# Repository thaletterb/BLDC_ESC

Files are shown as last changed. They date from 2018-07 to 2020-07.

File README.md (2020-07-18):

## MSP430 Brushless DC Motor Electronic Speed Controller 

Development of an MSP430 based electronic speed controller. 
* Controls a BLDC electric motor for speed/torque
* Trapezoidal control scheme (6 Step Commutation)

## Background 

* Electronic Speed Control (ESC) is an electronic circuit that controls and regulates the speed of an electric motor. 
* SIMONK ESCs are commonly used for applications such as quadcopters or RC cars
* The purpose of this project is to develop an MSP430 based ESC which replicates the functionality of an off the shelf controller

## Hardware Architecture 

* Current implementation:
  * HW Revision 2
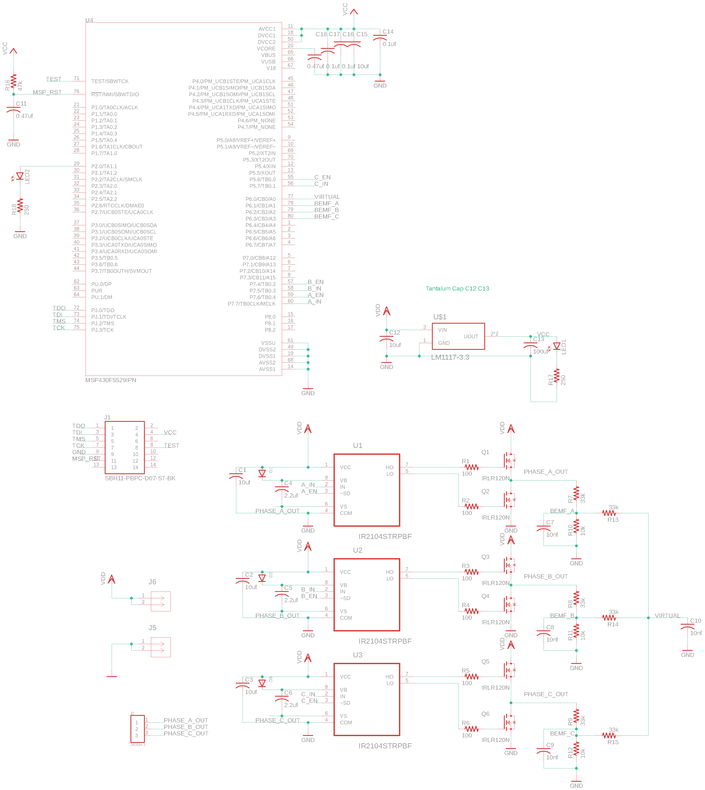
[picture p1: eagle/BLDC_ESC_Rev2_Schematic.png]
Title
  * 

* Revision History
  * Revision 2 
    * 1 MSP430F5529 PCBA 
    * 1 LHI 2212 920KV Brushless Motor
    * 6 IRLR120N MOSFET N Channel 
    * 3 IR2104S IC Gate Driver 
  * Revision 1 
    * 1 MSP430F5529 Launchpad
    * 1 LHI 2212 920KV Brushless Motor
    * 1 SIMONK 30A ESC
    * 1 Potentiometer to act as throttle input

## Software Architecture

* TI-RTOS
* Current phase of implementation consists of:
  * Using MSP430 to generate varying width PWM signals to the SIMONK ESC
  * Potentiometer attached to analog input P6.1
* Periodics
  * 50Hz CLK

## Software Requirements

Software is based on MSP430F5529 launchpad, running TI-RTOS.

* Code Composer Studio (ver 8.3.1)
  * http://www.ti.com/tool/CCSTUDIO
* TI-RTOS MSP43x 2.20.00.06 
  * http://software-dl.ti.com/dsps/dsps_public_sw/sdo_sb/targetcontent/tirtos/index.html

## References
* https://en.wikipedia.org/wiki/Electronic_speed_control 
* https://www.instructables.com/id/Make-Your-Own-ESC/ 
* http://www.ti.com/lit/ug/spruhu4e/spruhu4e.pdf
* https://simple-circuit.com/arduino-sensorless-bldc-motor-controller-esc/

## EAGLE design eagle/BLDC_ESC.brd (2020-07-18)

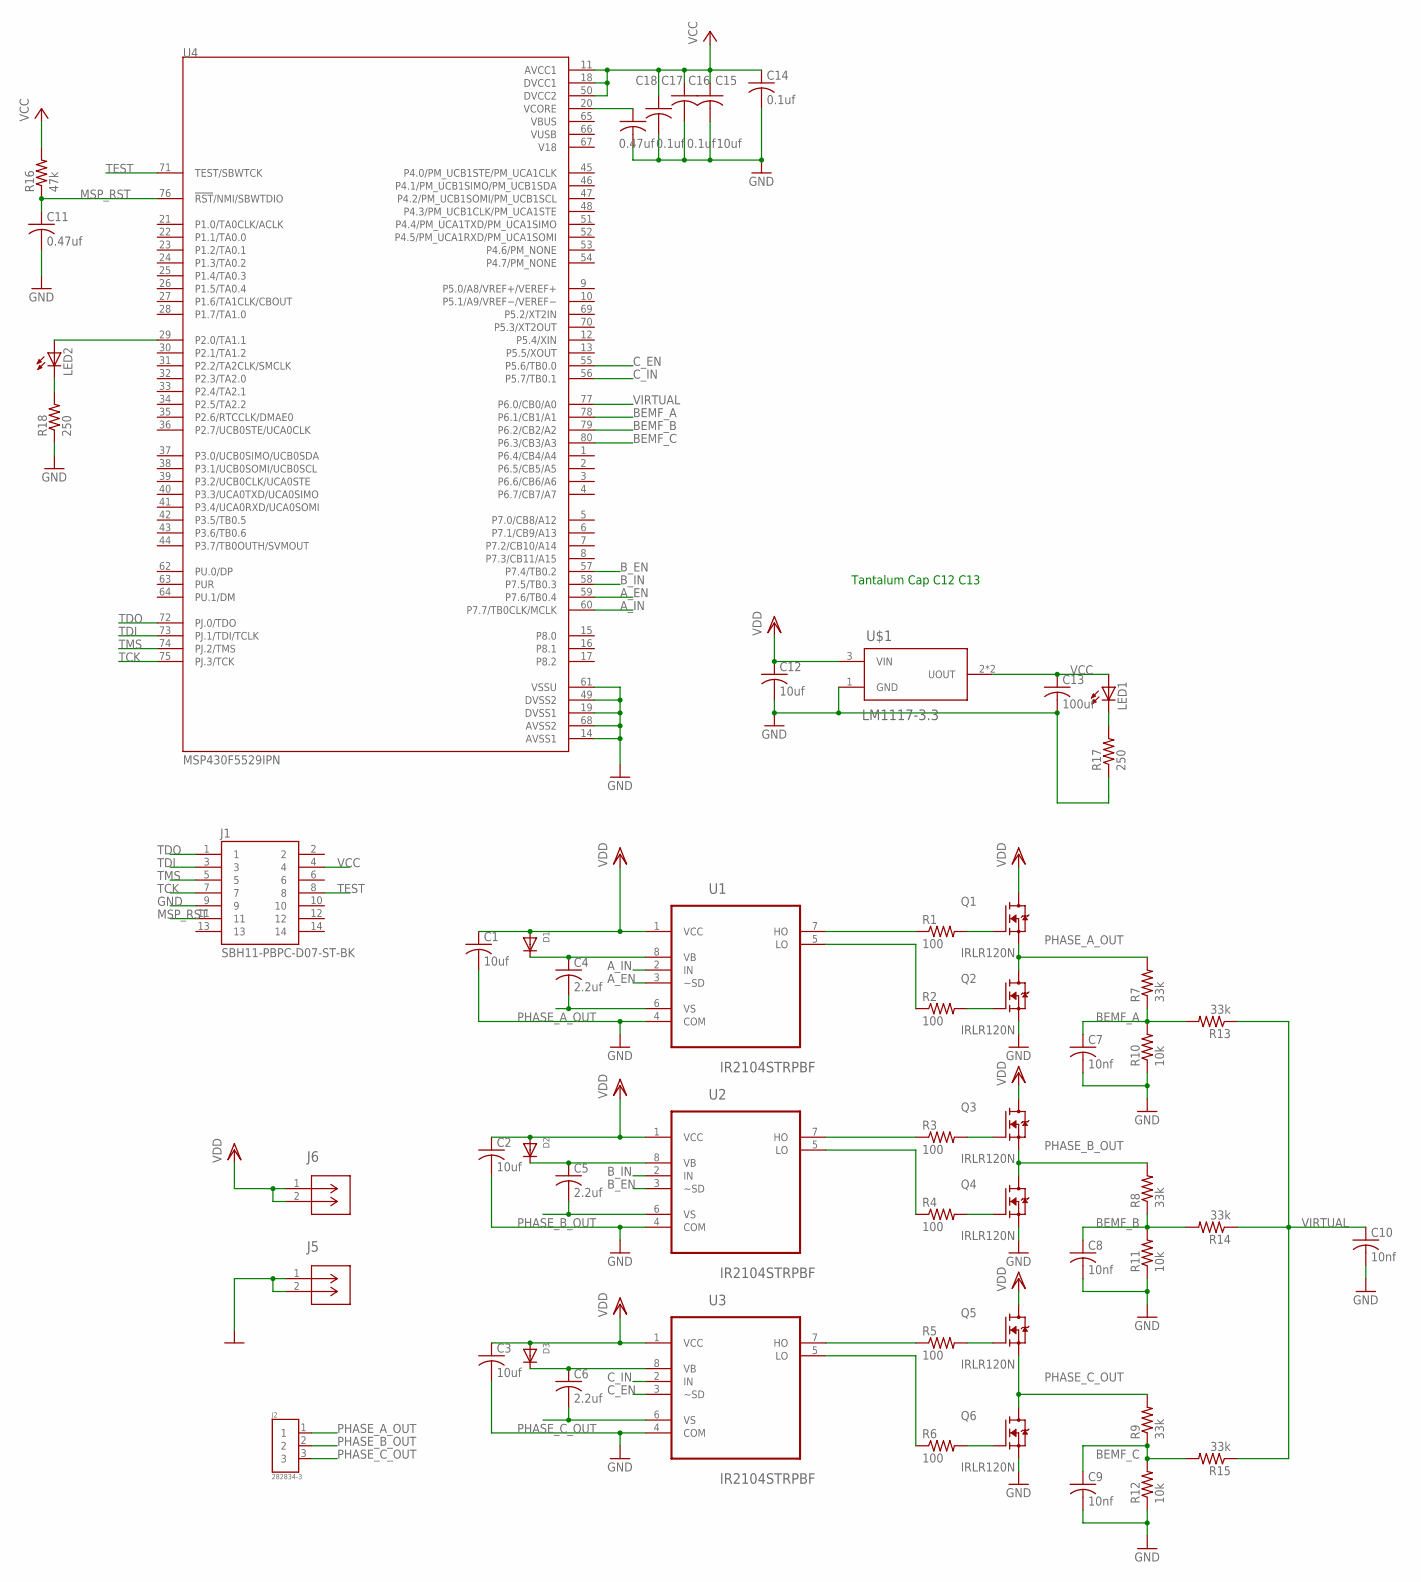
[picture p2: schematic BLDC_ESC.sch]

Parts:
C1, C2, C3: 10uf; C0805K
C4, C5, C6: 2.2uf; C0805K
C7, C8, C9, C10: 10nf; C0805
C11, C18: 0.47uf; C0805
C12, C15: 10uf; C0805
C13: 100uf; C0805
C14, C16, C17: 0.1uf; C0805
D1, D2, D3: DIODESOD-123; SOD-123
J1: SBH11-PBPC-D07-ST-BK; SULLINS_SBH11-PBPC-D07-ST-BK
J2: 282834-3; TE_282834-3
J5, J6: 105-1103-001; CONN_105-1102-001
LED1, LED2: LEDCHIPLED_0805; CHIPLED_0805
Q1, Q2, Q3, Q4, Q5, Q6: IRLR120N; DPAK229P990X239-3N
R1, R2, R3, R4, R5, R6: 100; R0805
R7, R8, R9, R13, R14, R15: 33k; R0805
R10, R11, R12: 10k; R0805
R16: 47k; M0805
R17, R18: 250; R0805
U1, U2, U3: IR2104STRPBF; SOIC127P600X175-8N
U4: MSP430F5529IPN; QFP50P1400X1400X160-80N
U$1: LM1117-3.3; SOT-223

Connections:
A_EN: U1.3 (~SD), U4.59 (P7.6/TB0.4)
A_IN: U1.2 (IN), U4.60 (P7.7/TB0CLK/MCLK)
BEMF_A: C7.1, R7.1, R10.2, R13.2, U4.78 (P6.1/CB1/A1)
BEMF_B: C8.1, R8.1, R11.2, R14.2, U4.79 (P6.2/CB2/A2)
BEMF_C: C9.1, R9.1, R12.2, R15.2, U4.80 (P6.3/CB3/A3)
B_EN: U2.3 (~SD), U4.57 (P7.4/TB0.2)
B_IN: U2.2 (IN), U4.58 (P7.5/TB0.3)
C_EN: U3.3 (~SD), U4.55 (P5.6/TB0.0)
C_IN: U3.2 (IN), U4.56 (P5.7/TB0.1)
GND: C1.2, C2.2, C3.2, C7.2, C8.2, C9.2, C10.2, C11.2, C12.2, C13.2, C14.2, C15.2, C16.2, C17.2, C18.2, J1.9, J5.1, J5.2, Q2.2 (S), Q4.2 (S), Q6.2 (S), R10.1, R11.1, R12.1, R17.1, R18.1, U1.4 (COM), U2.4 (COM), U3.4 (COM), U4.14 (AVSS1), U4.19 (DVSS1), U4.49 (DVSS2), U4.61 (VSSU), U4.68 (AVSS2), U$1.1 (GND)
MSP_RST: C11.1, J1.11, R16.1, U4.76 (!RST!/NMI/SBWTDIO)
unnamed: Q1.1 (G), R1.2
unnamed: R1.1, U1.7 (HO)
unnamed: R2.1, U1.5 (LO)
unnamed: Q2.1 (G), R2.2
unnamed: C6.1, D3.C, U3.8 (VB)
unnamed: C5.1, D2.C, U2.8 (VB)
unnamed: C4.1, D1.C, U1.8 (VB)
unnamed: R3.1, U2.7 (HO)
unnamed: Q3.1 (G), R3.2
unnamed: R4.1, U2.5 (LO)
unnamed: Q4.1 (G), R4.2
unnamed: R5.1, U3.7 (HO)
unnamed: Q5.1 (G), R5.2
unnamed: R6.1, U3.5 (LO)
unnamed: Q6.1 (G), R6.2
unnamed: LED1.C, R17.2
unnamed: LED2.A, U4.29 (P2.0/TA1.1)
unnamed: LED2.C, R18.2
unnamed: C18.1, U4.20 (VCORE)
PHASE_A_OUT: C4.2, J2.1, Q1.2 (S), Q2.3 (D), R7.2, U1.6 (VS)
PHASE_B_OUT: C5.2, J2.2, Q3.2 (S), Q4.3 (D), R8.2, U2.6 (VS)
PHASE_C_OUT: C6.2, J2.3, Q5.2 (S), Q6.3 (D), R9.2, U3.6 (VS)
TCK: J1.7, U4.75 (PJ.3/TCK)
TDI: J1.3, U4.73 (PJ.1/TDI/TCLK)
TDO: J1.1, U4.72 (PJ.0/TDO)
TEST: J1.8, U4.71 (TEST/SBWTCK)
TMS: J1.5, U4.74 (PJ.2/TMS)
V18: U4.67 (V18)
VBUS: U4.65 (VBUS)
VCC: C13.1, C14.1, C15.1, C16.1, C17.1, J1.4, LED1.A, R16.2, U4.11 (AVCC1), U4.18 (DVCC1), U4.50 (DVCC2), U$1.2 (UOUT), U$1.4 (UOUT)
VDD: C1.1, C2.1, C3.1, C12.1, D1.A, D2.A, D3.A, J6.1, J6.2, Q1.3 (D), Q3.3 (D), Q5.3 (D), U1.1 (VCC), U2.1 (VCC), U3.1 (VCC), U$1.3 (VIN)
VIRTUAL: C10.1, R13.1, R14.1, R15.1, U4.77 (P6.0/CB0/A0)
VUSB: U4.66 (VUSB)

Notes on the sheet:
Tantalum Cap C12 C13

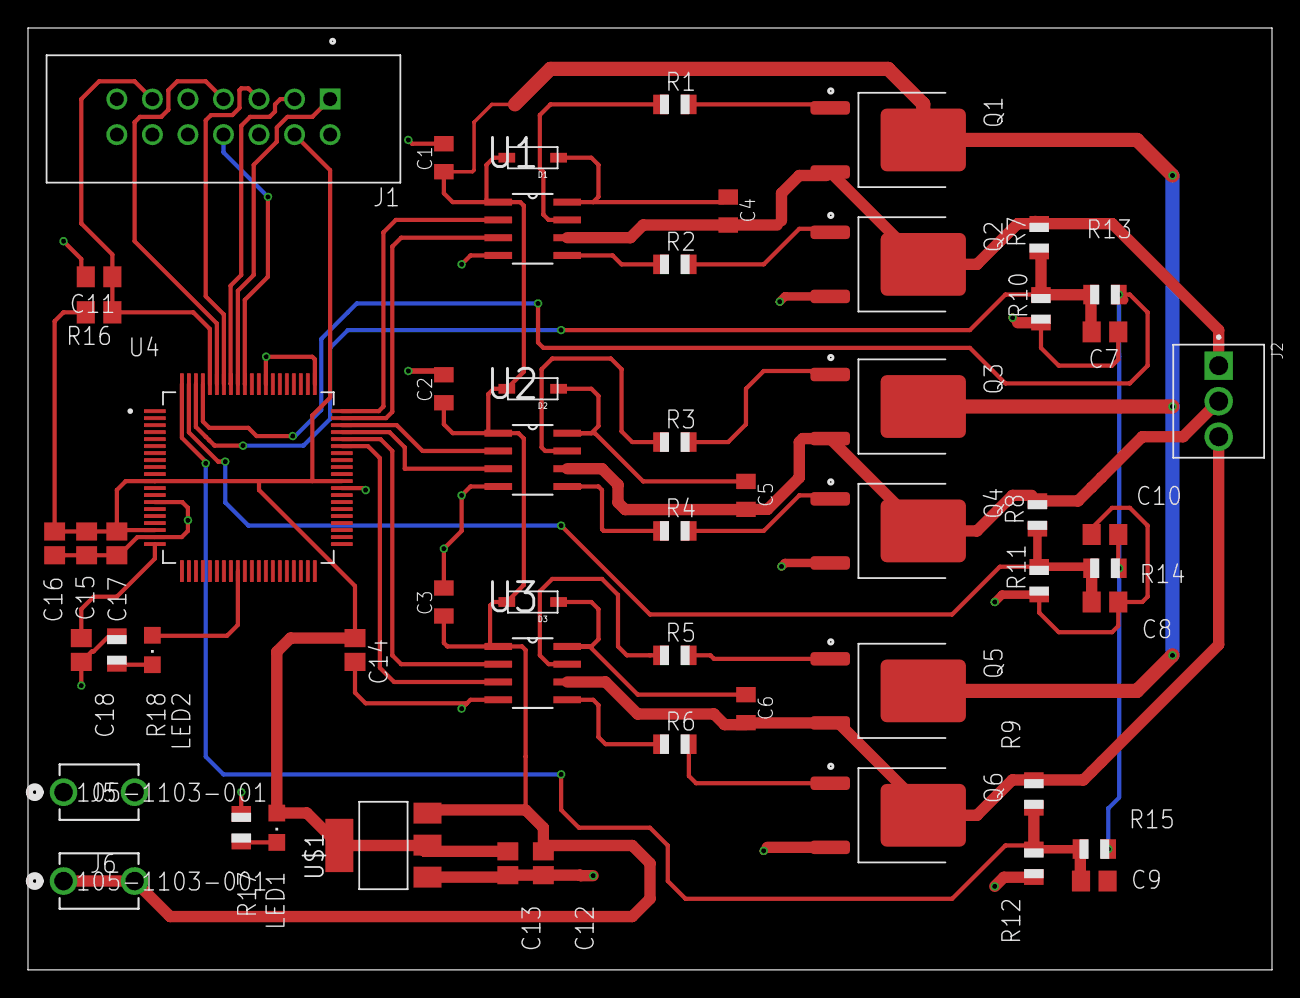
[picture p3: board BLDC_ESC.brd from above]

Board: 2 copper layers, 88.9 x 67.3 mm, 56 parts (0 on the bottom side), 41 nets.

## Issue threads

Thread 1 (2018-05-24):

Enabling toggling of GPIOs besides LEDs

thaletterb, 2018-05-24:
Need to be able to send a varying pulse width to the ESC every 20ms

1. Use GPIOs for simple first approach.
    * Only LEDs currently toggle - Figure out how to use any of the other GPIOs broken out `1.6`?
    * Determine accuracy of pulse widths with this approach

thaletterb, 2018-05-26:
https://github.com/thaletterb/BLDC_ESC/pull/2

Closed 2018-05-26.

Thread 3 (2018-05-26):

Setup PWM to send pulses to ESC

thaletterb, 2018-05-26:
* Use TIMERA P1.2 `TA0.1`
* 20ms period / 50hz frequency
* Use SMCLK

thaletterb, 2018-06-03:
Merged 30e38fb966be4494d60473bf33b3eda664b48ba7

Closed 2018-06-03.

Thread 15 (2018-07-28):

Create throttle module

thaletterb, 2018-07-28:
Proof of concept throttle module.
* Should use a combination of ADC and GPIO
  * ADC connected to potentiometer used to scale the ESC's input PWM duty cycle from 1.0-2.0ms
  * GPIO button as on/off

thaletterb, 2018-08-01:
https://github.com/thaletterb/BLDC_ESC/pull/20

Closed 2018-08-01.

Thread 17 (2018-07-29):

Create ADC driver/lib

thaletterb, 2018-07-29:

thaletterb, 2018-07-30:
Implemented - https://github.com/thaletterb/BLDC_ESC/commit/ef1179c509440fa351b9eebd302352afc36fe6b5

Closed 2018-07-30.

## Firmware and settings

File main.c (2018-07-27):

/*
 * Copyright (c) 2015, Texas Instruments Incorporated
 * All rights reserved.
 *
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
 * *  Redistributions of source code must retain the above copyright
 *    notice, this list of conditions and the following disclaimer.
 *
 * *  Redistributions in binary form must reproduce the above copyright
 *    notice, this list of conditions and the following disclaimer in the
 *    documentation and/or other materials provided with the distribution.
 *
 * *  Neither the name of Texas Instruments Incorporated nor the names of
 *    its contributors may be used to endorse or promote products derived
 *    from this software without specific prior written permission.
 *
 * THIS SOFTWARE IS PROVIDED BY THE COPYRIGHT HOLDERS AND CONTRIBUTORS "AS IS"
 * AND ANY EXPRESS OR IMPLIED WARRANTIES, INCLUDING, BUT NOT LIMITED TO,
 * THE IMPLIED WARRANTIES OF MERCHANTABILITY AND FITNESS FOR A PARTICULAR
 * PURPOSE ARE DISCLAIMED. IN NO EVENT SHALL THE COPYRIGHT OWNER OR
 * CONTRIBUTORS BE LIABLE FOR ANY DIRECT, INDIRECT, INCIDENTAL, SPECIAL,
 * EXEMPLARY, OR CONSEQUENTIAL DAMAGES (INCLUDING, BUT NOT LIMITED TO,
 * PROCUREMENT OF SUBSTITUTE GOODS OR SERVICES; LOSS OF USE, DATA, OR PROFITS;
 * OR BUSINESS INTERRUPTION) HOWEVER CAUSED AND ON ANY THEORY OF LIABILITY,
 * WHETHER IN CONTRACT, STRICT LIABILITY, OR TORT (INCLUDING NEGLIGENCE OR
 * OTHERWISE) ARISING IN ANY WAY OUT OF THE USE OF THIS SOFTWARE,
 * EVEN IF ADVISED OF THE POSSIBILITY OF SUCH DAMAGE.
 */

/*
 *  ======== empty_min.c ========
 */
/* XDCtools Header files */
#include <xdc/std.h>
#include <xdc/cfg/global.h>

/* BIOS Header files */
#include <ti/sysbios/BIOS.h>
#include <ti/sysbios/knl/Task.h>
#include <ti/sysbios/knl/Semaphore.h>


/* TI-RTOS Header files */
#include <ti/drivers/GPIO.h>

/* Board Header file */
#include "Board.h"

#include "ESC.h"


/*
 *  ======== main ========
 */
int main(void)
{
    /* Call board init functions */
    Board_initGeneral();
    Board_initGPIO();

    // Initialize all system modules
    ESC_init();

    /* Start BIOS */
    BIOS_start();

    return (0);
}

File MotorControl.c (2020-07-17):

/*
 * MotorControl.c
 *
 *  Created on: Jun 16, 2018
 *      Author: brianvuong
 */

#include "MotorControl.h"
#include "PWM.h"

#include <string.h>

/* TI-RTOS Header files */
#include <ti/drivers/GPIO.h>
#include "board.h"

// TODO!
#include <msp430.h>
#include <timer_a.h>

/*
 * Typedefs
 */
typedef struct mc_s
{
    double  pulseTimeOnMS;
    int     stateTimer50hz;

    uint8_t index;
}mc_s;

typedef enum
{
    MC_STEP_0,
    MC_STEP_1,
    MC_STEP_2,
    MC_STEP_3,
    MC_STEP_4,
    MC_STEP_5,

    MC_NUM_STEPS
} mc_steps_t;

/*
 * Global Variables
 */
MC_S MC;

/*
 * Local Variables
 */
mc_s mc;

/*
 * Private Functions
 */

/*
 * Commutation functions
 * Step:            Active Switches:
 * -----            ----------------
 * 0                PH1 HI, PH2 LO
 * 1                PH1 HI, PH3 LO
 * 2                PH2 HI, PH3 LO
 * 3                PH2 HI, PH1 LO
 * 4                PH3 HI, PH1 LO
 * 5                PH3 HI, PH2 LO
 */
static void phaseOneOff(void)
{
    GPIO_write(Board_PH1_EN, 0);
    GPIO_write(Board_PH1_IN, 0);
}

static void phaseTwoOff(void)
{
    GPIO_write(Board_PH2_EN, 0);
    GPIO_write(Board_PH2_IN, 0);
}

static void phaseThreeOff(void)
{
    GPIO_write(Board_PH3_EN, 0);
    GPIO_write(Board_PH3_IN, 0);
}

static void allOff(void)
{
    GPIO_write(Board_PH1_EN, 0);
    GPIO_write(Board_PH2_EN, 0);
    GPIO_write(Board_PH3_EN, 0);

    GPIO_write(Board_PH1_IN, 0);
    GPIO_write(Board_PH2_IN, 0);
    GPIO_write(Board_PH3_IN, 0);
}

// PH1 HI, PH2 LO
static void step0(void)
{
    phaseThreeOff();

    // Disable PWM on IN2/IN3
    TA0CCR1     = 8U;
    TA0CCR2     = 0U;
    TA0CCR3     = 0U;

    GPIO_write(Board_PH1_EN, 1);
    GPIO_write(Board_PH2_EN, 1);

    GPIO_write(Board_PH1_IN, 1);
    GPIO_write(Board_PH2_IN, 0);
}

// PH1 HI, PH3 LO
static void step1(void)
{
    phaseTwoOff();

    // Disable PWM on IN2/IN3
    TA0CCR1     = 8U;
    TA0CCR2     = 0U;
    TA0CCR3     = 0U;

    GPIO_write(Board_PH1_EN, 1);
    GPIO_write(Board_PH3_EN, 1);

    GPIO_write(Board_PH1_IN, 1);
    GPIO_write(Board_PH3_IN, 0);
}

// PH2 HI, PH3 LO
static void step2(void)
{
    phaseOneOff();

    // Disable PWM on IN1/IN3
    TA0CCR1     = 0U;
    TA0CCR2     = 8U;
    TA0CCR3     = 0U;

    GPIO_write(Board_PH2_EN, 1);
    GPIO_write(Board_PH3_EN, 1);

    GPIO_write(Board_PH2_IN, 1);
    GPIO_write(Board_PH3_IN, 0);
}

// PH2 HI, PH1 LO
static void step3(void)
{
    phaseThreeOff();

    // Disable PWM on IN1/IN3
    TA0CCR1     = 0U;
    TA0CCR2     = 8U;
    TA0CCR3     = 0U;

    GPIO_write(Board_PH2_EN, 1);
    GPIO_write(Board_PH1_EN, 1);

    GPIO_write(Board_PH2_IN, 1);
    GPIO_write(Board_PH1_IN, 0);
}

// PH3 HI, PH1 LO
static void step4(void)
{
    phaseTwoOff();

    // Disable PWM on IN1/IN2
    TA0CCR1     = 0U;
    TA0CCR2     = 0U;
    TA0CCR3     = 8U;

    GPIO_write(Board_PH3_EN, 1);
    GPIO_write(Board_PH1_EN, 1);

    GPIO_write(Board_PH3_IN, 1);
    GPIO_write(Board_PH1_IN, 0);
}

// PH3 HI, PH2 LO
static void step5(void)
{
    phaseOneOff();

    // Disable PWM on IN1/IN2
    TA0CCR1     = 0U;
    TA0CCR2     = 0U;
    TA0CCR3     = 8U;

    GPIO_write(Board_PH3_EN, 1);
    GPIO_write(Board_PH2_EN, 1);

    GPIO_write(Board_PH3_IN, 1);
    GPIO_write(Board_PH2_IN, 0);
}

// Should only be called on transition between MC.states
static void mc_sendPulseToESC(void)
{
    PWM_setDutyCycleTimeOn(mc.pulseTimeOnMS);
}


// Process state machine
static void mc_processStates_50Hz(void)
{
    switch(MC.state)
    {
        case MC_ESC_ARMING:
            if(mc.stateTimer50hz++ == 250)
            {
                MC.state = MC_ESC_ARMED;

                mc.stateTimer50hz = 0;
                mc.pulseTimeOnMS = 1.10;
                mc_sendPulseToESC();
            }
            break;
        case MC_ESC_ARMED:
                mc_sendPulseToESC();
            break;
        case MC_ESC_DISABLED:
        default:
            break;
    }
}


/*
 * Public Functions
 */
void MC_init(void)
{
    memset(&MC, 0, sizeof(MC));
    MC.state = MC_ESC_ARMING;
}

void MC_setPulseWidth(float timeOnMS)
{
    mc.pulseTimeOnMS = timeOnMS;
}

void MC_50Hz_CLK(void)
{
    // Process state machine
    //mc_processStates_50Hz(); // TODO: Still needed?
    // Send appropriate pulse
    switch(mc.index)
    {
        case 0:
            step0();
            break;
        case 1:
            step1();
            break;
        case 2:
            step2();
            break;
        case 3:
            step3();
            break;
        case 4:
            step4();
            break;
        case 5:
            step5();
            break;
    }
    if(++mc.index > 5U)
    {
        mc.index = 0U;
    }
}

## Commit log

2018-05-26 Use GPIO as basic PWM pulse * Enable GPIO1_6 as output * Use semaphore to send task * Started using PWM - WIP
    [main.cfg]
2018-06-03 Create PWM module
2018-07-25 Implement Motor Control Module * Create header and module file * Implement first pass of state machine * Use module within main * Demo code: Toggle through different states/modes
2018-07-26 Create top level ESC module * Create new module * Update 50hz CLK callback function * Use new module in main
    [main.cfg]
2018-07-30 Create ADC driver * Default initialization to P6.1 * Demo blink LED when ADC input is 1/2 resolution
2018-07-31 Create Throttle Module * Create new module and interface * Control PWM based on throttle position
2018-11-23 Implement Basic 6 step commutation * Configure new GPIOs and PWM * Uses hardcoded 8us on and 42us off for PWM chopping
2020-07-17 Create 1Hz Clock Periodic
    [main.cfg]

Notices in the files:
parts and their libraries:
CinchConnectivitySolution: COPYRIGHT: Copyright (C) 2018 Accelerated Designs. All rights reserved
